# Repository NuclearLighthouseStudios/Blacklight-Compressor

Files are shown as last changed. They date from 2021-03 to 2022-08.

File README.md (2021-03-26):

# Blacklight UV LED Compressor

These are the KiCAD schematics and board layout filed for my Blacklight UV LED Compressor.  
If you just want the Gerber files or a PDF of the schematic check out the releases tab for downloads.

This PCB should be easily manufacturable with most online PCB houses by just uploading the gerber files.

This board is designed to be used with my Switchboard Pedal IO PCB which you can find [here](https://github.com/NuclearLighthouseStudios/Switchboard).

## BOM

| Reference | Quantity | Value  | Description |
| :--- | ---: | -----: | :--- |
| C1 C4 C6 | 3 | 100n | WIMA MKS2 63V |
| C2 C5 | 2 | 1µ | WIMA MKS2 50V |
| C3 | 1 | 470n | WIMA MKS2 50V |
| C7 | 1 | 10µ | Electrolytic capacitor, 16V |
| C8 C9 | 2 | 47µ | Electrolytic capacitor, 16V |
| D1 D2 | 2 | | UV LED 400nm, ~3.2V forward voltage drop |
| | 2 | | 7.5mm LED standoff |
| J1 | 1 | | Pin Header, 6 pins, 2.54mm spacing |
| J2 | 1 | | DC Barrel Jack with internal switch |
| Q1 Q2 Q3 Q4 | 4 | BC547B | 0.1A Ic, 45V Vce, Small Signal NPN Transistor, TO-92 |
| R1 R2 R5 | 3 | 1M | Metal film resistor 1%, DIN 0207 |
| R3 R7 | 2 | 10k | Metal film resistor 1%, DIN 0207 |
| R4 | 1 | 4.7k | Metal film resistor 1%, DIN 0207 |
| R6 R10 R13  | 3 | 100k | Metal film resistor 1%, DIN 0207 |
| R8 | 1 | 100 | Metal film resistor 1%, DIN 0207 |
| R9 | 1 | 39k | Metal film resistor 1%, DIN 0207 |
| R11 | 1 | 47k | Metal film resistor 1%, DIN 0207 |
| R12 | 1 | 2.7k | Metal film resistor 1%, DIN 0207 |
| R14 | 1 | 82k | Metal film resistor 1%, DIN 0207 |
| R15 R16 | 2 | 1k | Metal film resistor 1%, DIN 0207 |
| RV1 RV2 | 2 | 100k | Alps RK09K1130C94 Potentiometer |

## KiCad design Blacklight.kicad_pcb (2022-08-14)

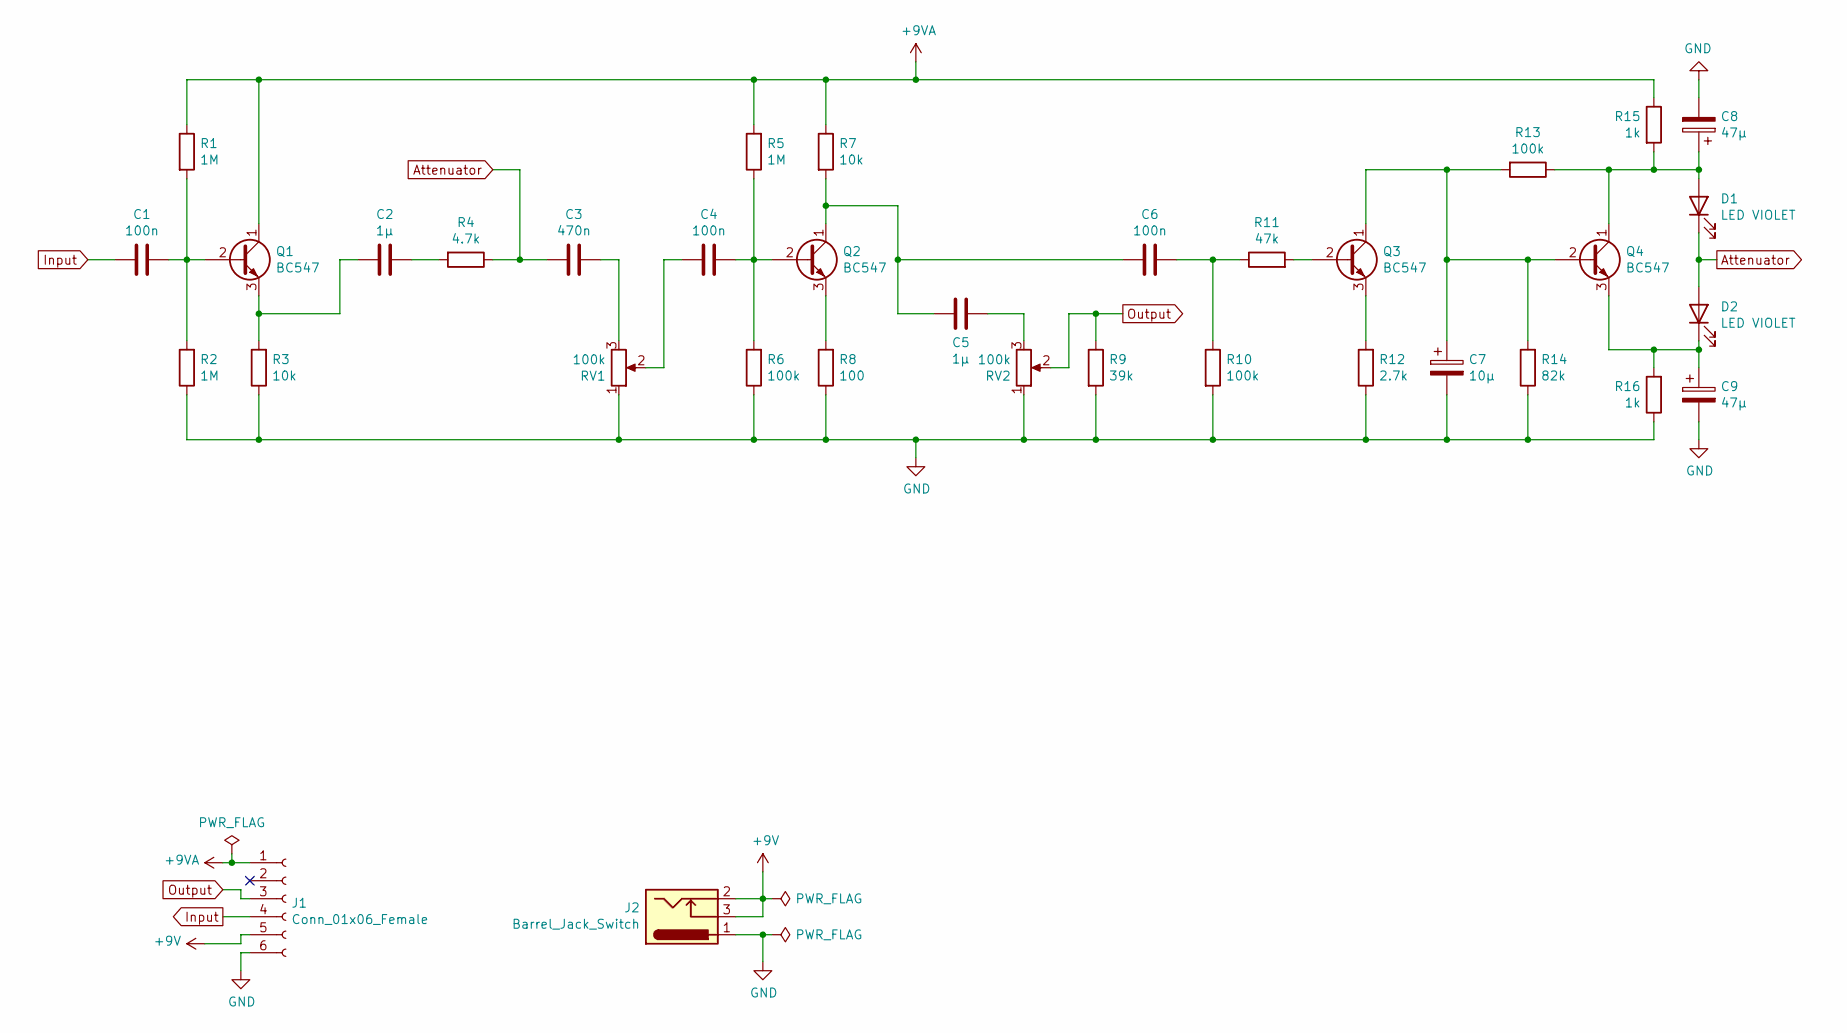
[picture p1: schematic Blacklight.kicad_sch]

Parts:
C1, C4, C6: 100n; C_Rect_L7.2mm_W2.5mm_P5.00mm_FKS2_FKP2_MKS2_MKP2
C2, C5: 1µ; C_Rect_L7.2mm_W4.5mm_P5.00mm_FKS2_FKP2_MKS2_MKP2
C3: 470n; C_Rect_L7.2mm_W3.5mm_P5.00mm_FKS2_FKP2_MKS2_MKP2
C7: 10µ; CP_Radial_D5.0mm_P2.50mm
C8, C9: 47µ; CP_Radial_D5.0mm_P2.50mm
D1, D2: LED VIOLET; LED_D5.0mm
J1: Conn_01x06_Female; PinHeader_1x06_P2.54mm_Vertical
J2: Barrel_Jack_Switch; BarrelJack_Horizontal_Short
Q1, Q2, Q3, Q4: BC547; TO-92_Wide
R1, R2, R5: 1M; R_Axial_DIN0207_L6.3mm_D2.5mm_P2.54mm_Vertical
R3, R7: 10k; R_Axial_DIN0207_L6.3mm_D2.5mm_P2.54mm_Vertical
R4: 4.7k; R_Axial_DIN0207_L6.3mm_D2.5mm_P2.54mm_Vertical
R6, R10: 100k; R_Axial_DIN0207_L6.3mm_D2.5mm_P2.54mm_Vertical
R8: 100; R_Axial_DIN0207_L6.3mm_D2.5mm_P2.54mm_Vertical
R9: 39k; R_Axial_DIN0207_L6.3mm_D2.5mm_P7.62mm_Horizontal
R11: 47k; R_Axial_DIN0207_L6.3mm_D2.5mm_P2.54mm_Vertical
R12: 2.7k; R_Axial_DIN0207_L6.3mm_D2.5mm_P2.54mm_Vertical
R13: 100k; R_Axial_DIN0207_L6.3mm_D2.5mm_P7.62mm_Horizontal
R14: 82k; R_Axial_DIN0207_L6.3mm_D2.5mm_P2.54mm_Vertical
R15, R16: 1k; R_Axial_DIN0207_L6.3mm_D2.5mm_P2.54mm_Vertical
RV1, RV2: 100k; Potentiometer_Alps_RK09K_Single_Vertical

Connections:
+9V: J1.5, J2.2, J2.3
+9VA: J1.1, Q1.1 (C), R1.1, R5.2, R7.1, R15.1
Attenuator: C3.2, D1.1 (K), D2.2 (A), R4.1
GND: C7.2, C8.2, C9.2, J1.6, J2.1, R2.1, R3.1, R6.1, R8.1, R9.2, R10.2, R12.1, R14.1, R16.1, RV1.1, RV2.1
Input: C1.2, J1.4
unnamed: C1.1, Q1.2 (B), R1.2, R2.2
unnamed: C2.1, R4.2
unnamed: C2.2, Q1.3 (E), R3.2
unnamed: C3.1, RV1.3
unnamed: C4.1, Q2.2 (B), R5.1, R6.2
unnamed: C4.2, RV1.2
unnamed: C5.1, RV2.3
unnamed: C5.2, C6.2, Q2.1 (C), R7.2
unnamed: C6.1, R10.1, R11.1
unnamed: C7.1, Q3.1 (C), Q4.2 (B), R13.2, R14.2
unnamed: C8.1, D1.2 (A), Q4.1 (C), R13.1, R15.2
unnamed: C9.1, D2.1 (K), Q4.3 (E), R16.2
unnamed: Q2.3 (E), R8.2
unnamed: Q3.2 (B), R11.2
unnamed: Q3.3 (E), R12.2
Output: J1.3, R9.1, RV2.2

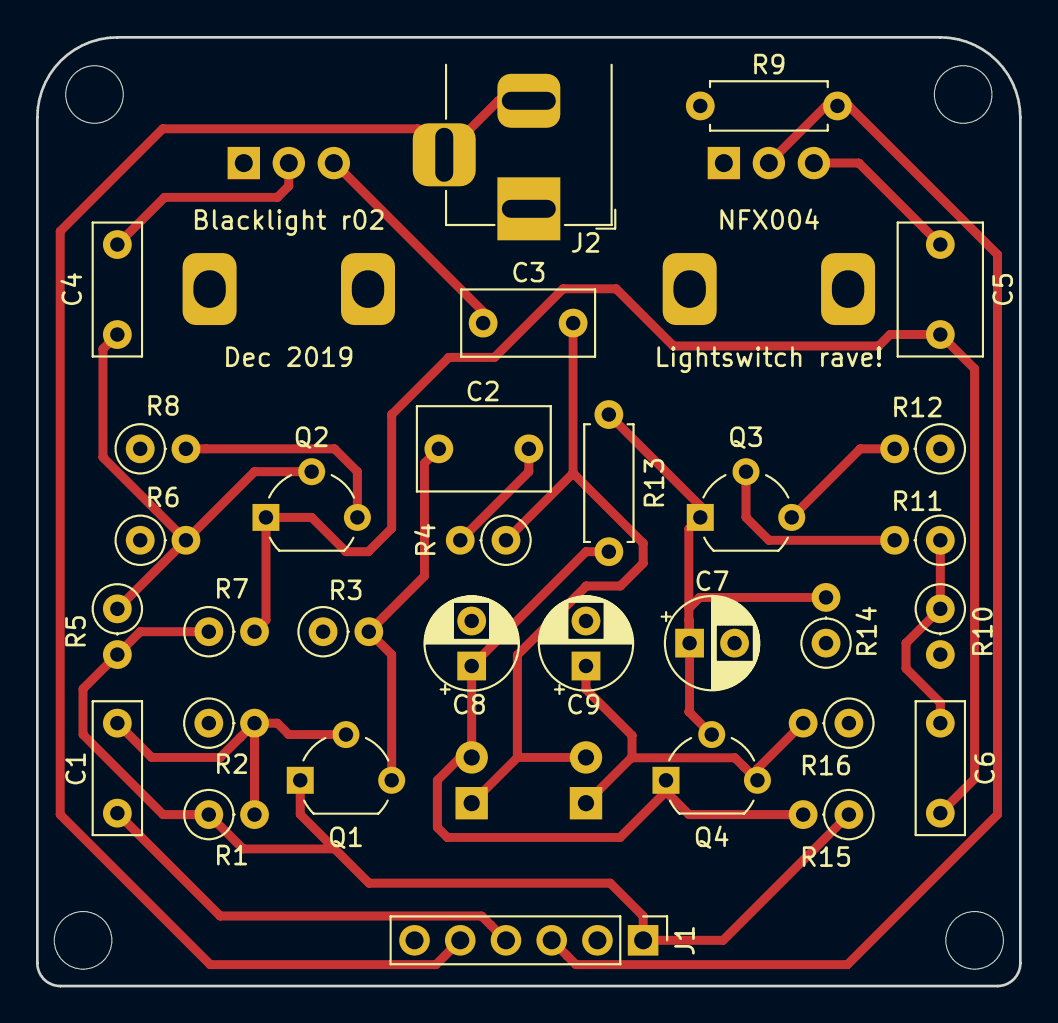
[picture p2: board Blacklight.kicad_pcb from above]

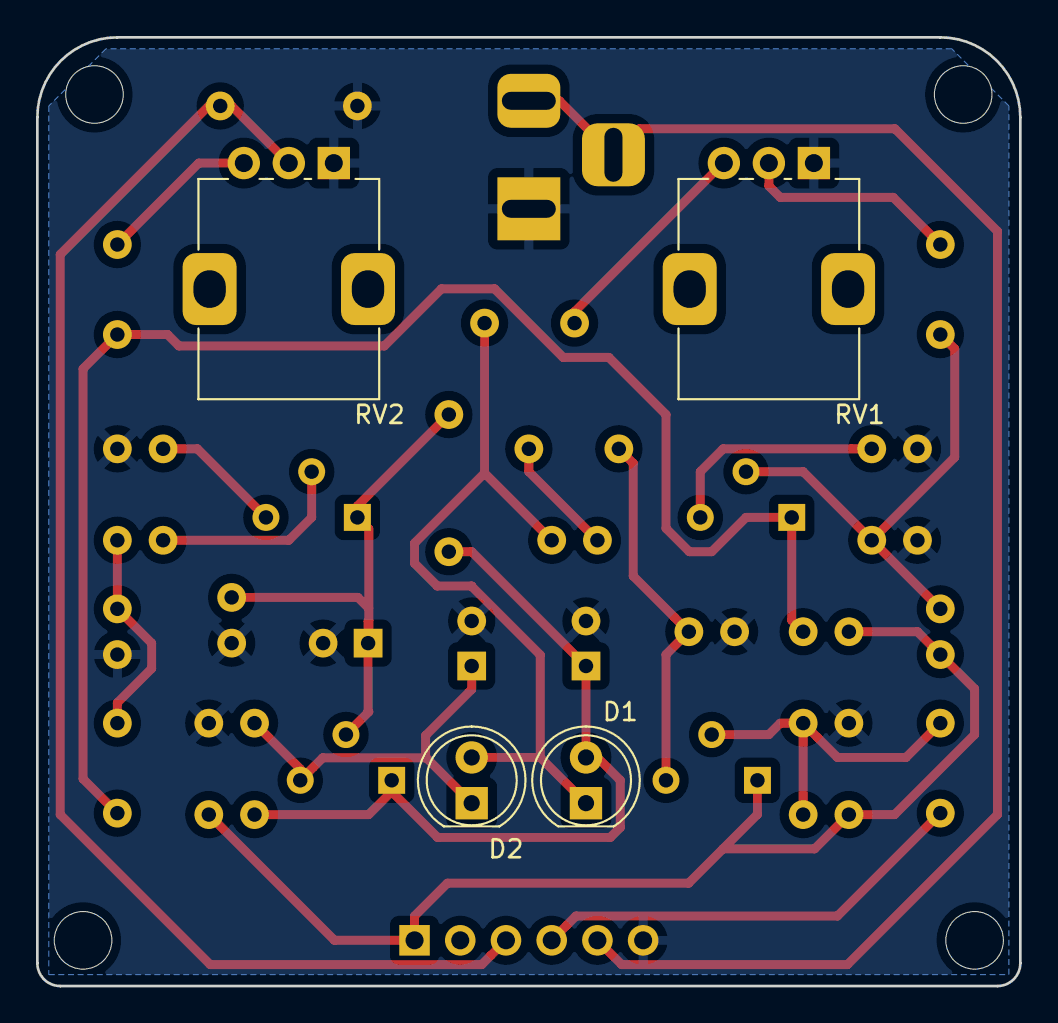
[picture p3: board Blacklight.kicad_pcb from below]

Board: 2 copper layers, 54.6 x 52.7 mm, 35 parts (4 on the bottom side), 21 nets.

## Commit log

2020-11-16 Initial commit! Yay!
    [Blacklight.kicad_pcb, Blacklight.sch]
2020-11-16 Improve BOM a little
2020-12-30 Fix mistake in BOM
2020-12-31 Update cap voltages
2021-03-26 Include LED standoffs in BOM
2022-08-14 Migrate to KiCAD 6
    [Blacklight.kicad_pcb, Blacklight.kicad_sch, Blacklight.sch]
2022-08-14 Update symbols/footprints
    [Blacklight.kicad_pcb, Blacklight.kicad_sch]
2022-08-14 Fix DRC errors
    [Blacklight.kicad_pcb]

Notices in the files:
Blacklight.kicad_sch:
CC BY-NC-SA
